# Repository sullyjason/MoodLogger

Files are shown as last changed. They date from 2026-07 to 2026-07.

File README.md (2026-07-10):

# MoodLogger

> **Attribution note:** This README (state documentation, roadmap) and the [Proposed v1 architecture](#proposed-v1-architecture-) section were drafted by **Claude (Fable 5)** on 2026-07-07 and updated as the design converged (part selection finalized 2026-07-10 with **Claude (Opus 4.8)**), based on the KiCad files in this repo, the project motivation, and the Picoclick-C3 reference project. Sections contributed by Claude are marked with 🤖. Hardware design decisions, part orders, prototypes, and project direction by Silvan Roth.

A tiny, battery-powered button logger. Press one of (at least) four buttons and the device wakes up, appends *which button was pressed at what time* to a CSV file, and goes back to sleep. To get the data, you plug the device into any USB host (cable or docking station) and it shows up as an ordinary USB flash drive — no companion app, no driver, no cloud. Grab the CSV, done.

## Design goals

- **≥ 4 buttons**, each press logged as `timestamp, button` to a CSV file
- **Wake on button press, sleep otherwise** — the device spends almost all of its life asleep
- **Battery life measured in months**: recharging should rarely, ideally almost never, be necessary
- **Host-agnostic data access**: the device enumerates as USB mass storage (a flash drive), so any OS can read the CSV without extra software
- **Accurate timestamps** from a dedicated RTC that keeps time even while the MCU sleeps

## Current state

Two prototype PCB revisions exist, both built around a **Seeed Studio XIAO ESP32-S3** module. They differ only in the RTC chip. Both are functional as prototypes but share one critical flaw (see [Known problems](#known-problems)).

### Common to both boards

- **MCU**: XIAO ESP32-S3 (U1) — provides USB-C, LiPo charging, and deep sleep
- **4 tactile buttons** (SW1–SW4, C&K PTS125) on XIAO pins D0–D3, each with a 10 k pull-up and 1 k series resistor, used as wake-up sources
- **I²C RTC** on D4/D5 (SDA/SCL)
- **CR1216 coin cell** (BT1) as RTC backup so time survives even when the main battery is empty
- **SPDT slide switch** (SW5) in the battery line as a hard power switch
- Main power from a LiPo cell on the XIAO's battery pads

### Version A — DS3231 (`EmotionTracker_DS32/`)

Board silkscreen: *EmotionLog v0 8.2025*

- **DS3231M** (U2, SOIC-16): temperature-compensated RTC with internal oscillator — very accurate, no external crystal needed, but comparatively power-hungry

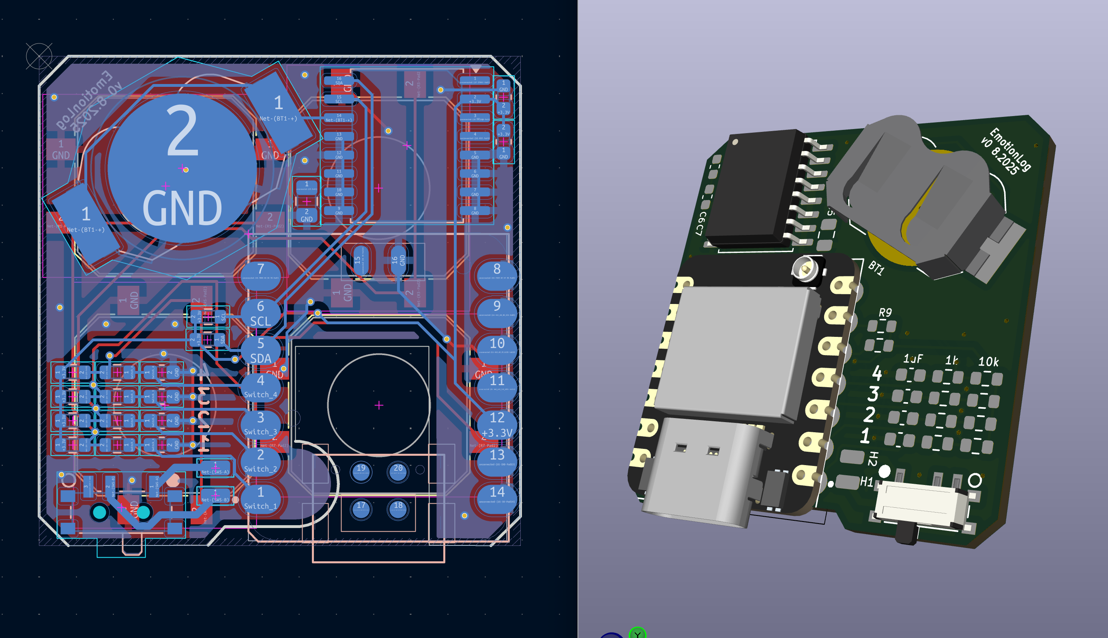
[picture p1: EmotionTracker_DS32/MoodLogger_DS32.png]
DS3231 version — layout and 3D render


### Version B — PCF8523 (`EmotionTracker_PCF8523/`)

- **PCF8523T** (U3, SOIC-8) with an external 32.768 kHz crystal (Y1) — much lower current draw than the DS3231, at the cost of needing the crystal and being less accurate over temperature
- Adds a status **LED** (D1), an extra small push button (SW6), and **BATin/BATout solder pads** in the battery path for measuring battery current / inserting protection circuitry
- `Dummy device/` contains a mechanical dummy PCB of the same outline for enclosure fitting

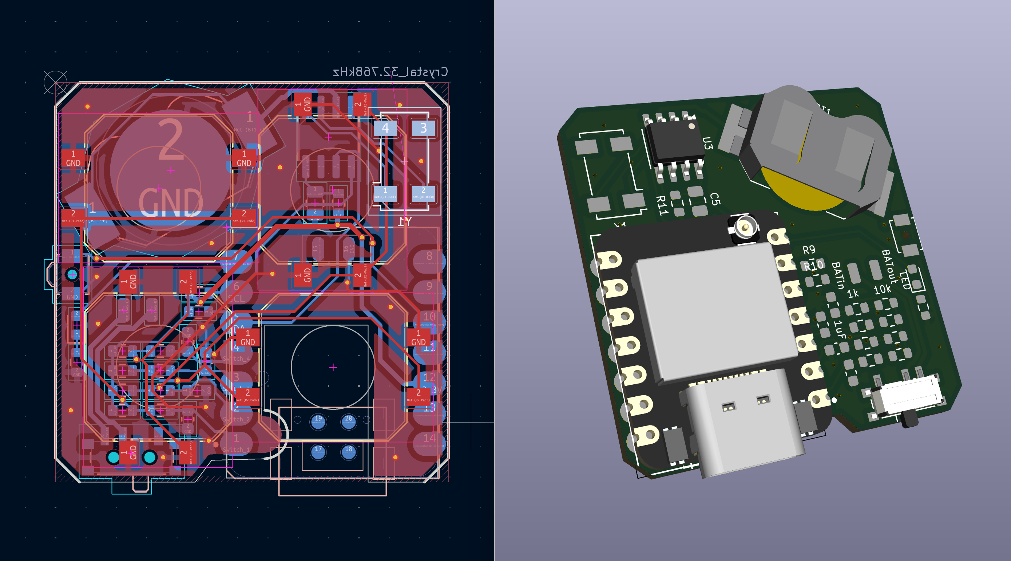
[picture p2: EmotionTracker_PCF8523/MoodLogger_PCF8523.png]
PCF8523 version — layout and 3D render


### Firmware (`Firmware/`)

Only a bring-up sketch exists so far: `Mood_track_v0/Mood_track_v0.ino` is a WS2812B/FastLED color-cycle test. The actual logging firmware (RTC, deep sleep, CSV writing, USB mass storage) has not been written yet.

## Known problems

**No battery over-discharge protection.** The XIAO ESP32-S3 has a charging circuit but no discharge cutoff, so when the device sits unused, the quiescent draw slowly pulls an unprotected LiPo below its safe minimum voltage and permanently damages it. This has already killed one battery. Nothing on either PCB revision protects against this.

**The XIAO is oversized for the job.** A full ESP32-S3 module with WiFi/BLE is overkill for "log a timestamp and sleep", and its deep-sleep and regulator overhead works against the battery-life goal.

## Roadmap

1. **Software safety first** (works on existing boards): monitor battery voltage from firmware and put the device into its lowest-power shutdown state below a cutoff threshold (with hysteresis so it doesn't oscillate near the limit). On the PCF8523 board the BATin/BATout pads can be used to hook up voltage sensing. This only *mitigates* the problem — even in deepest sleep the board still draws a few µA, so a fully drained device left on the shelf long enough can still damage the cell.
2. **Hardware protection**: add a proper battery protection IC (over-discharge cutoff) to the next board revision, or use protected cells in the meantime.
3. **Custom v1 design**: move away from the XIAO to a leaner MCU (the ATSAMD21G18) with a Picoclick-style soft power latch and native USB mass-storage, designed from the start around the goals above — see [Proposed v1 architecture](#proposed-v1-architecture-) below. Parts are ordered.

## Proposed v1 architecture 🤖

*Section author: Claude (Fable 5, refined with Opus 4.8), 2026-07-07 / 2026-07-10. Based on the boards above and the [Picoclick-C3](https://github.com/makermoekoe/Picoclick-C3) reference project (fork in `Reference Projects/`). Parts are selected and ordered but not yet built or bench-verified — treat as a design proposal, not a validated design.*

Proposed v1 block diagram

### Core idea: soft power latch instead of deep sleep

The key technique to adopt from the Picoclick is its **soft-latching power circuit**: between presses the MCU is not asleep, it is completely unpowered. A button press physically connects the battery to the regulator; the firmware's first act is to hold that connection via a latch GPIO, it logs the event, then releases the latch and the device switches itself off. The Picoclick C3 reaches **< 200 nA idle** this way — roughly three orders of magnitude below the XIAO's deep sleep — and it doubles as the discharge-protection strategy: a device that draws almost nothing cannot slowly kill its LiPo. A dedicated protection IC remains as the hard backstop.

### Why the ATSAMD21G18 (not the RP2040)

Both were considered — the deciding factor was PCB simplicity for a first custom board that may be partly hand-assembled:

- **Leaded package:** the SAMD21 is a TQFP-48 (0.5 mm, gullwing leads) — hand-solderable and inspectable. The RP2040 is a QFN-56 (0.4 mm, leadless + thermal pad) that effectively needs stencil + hot-air.
- **Fewer mandatory parts:** the SAMD21 has 256 KB internal flash and does **crystal-less USB** (clock recovery off the USB frame), so it needs no boot-flash and no crystal. The RP2040 has no internal flash (external QSPI flash is mandatory just to boot) and needs a 12 MHz crystal.
- **Native USB either way:** both enumerate cleanly as USB mass storage. (The Picoclick's own ESP32-C3 does *not* — its USB is a fixed Serial/JTAG peripheral — which is why its MCU was not reused.)

The RP2040 remains a reasonable alternative (faster boot for the latch, larger storage headroom); it just makes the board harder. The nRF52840 is the single-chip option if avoiding external flash matters more than assembly ease.

### Chosen parts (ordered)

| Block | Part | Notes |
|---|---|---|
| MCU | **ATSAMD21G18A** (TQFP-48) | 256 KB flash / 32 KB RAM, native USB, crystal-less USB via clock recovery |
| RTC | **RV-3028-C7** | ~45 nA, internal crystal, ±1 ppm; runs on the always-on rail so time survives with the MCU off. (DS3231M / PCF8523 are the higher-draw fallbacks proven on the existing boards) |
| Data storage | **W25Q32JVSSIM** (SOIC-8, 4 MB) | External SPI NOR for the FAT/CSV volume. Chosen over internal-flash-only for write endurance (~100 k vs ~25 k erase cycles) — each logged press is one FAT-metadata write, so endurance, not capacity, is the limit |
| Battery protection | **BQ29700DSER** | Over-discharge / over-current cutoff — the hard backstop for the failure that killed the prototype battery. Controller only: **needs an external dual N-channel MOSFET** (e.g. FS8205) in the cell's ground path |
| 3.3 V LDO | **AP2112K-3.3** | Sits *after* the latch, so its ~55 µA quiescent is irrelevant (only powered when the device is awake). Regulates the 3.0–4.2 V cell down to a SAMD21-safe 3.3 V |
| Charger | MCP73831-class | Charge current set by R_prog for the chosen small cell |
| Latch + button OR | P-FET high-side switch + Schottky diode-OR | Clone the Picoclick C3T latch topology (in the submodule) |

### Buttons, wake, and logging flow

Each of the four buttons does double duty: all are diode-ORed (Schottky) into the latch enable, so any press powers the board, and each also drives its own sense GPIO with a small RC hold so firmware can still read *which* button fired after boot. USB VBUS feeds the same latch OR, so plugging into any host wakes the device.

- **Log event**: boot → grab latch → read RTC over I²C → append `timestamp,button` to CSV (FatFs on NOR flash) → release latch.
- **USB attached**: enumerate as USB MSC exposing the FAT volume; pause logging while mounted.
- **Setting the clock without an app**: the firmware reads the modification timestamp of a marker file (e.g. the user saves an empty `settime.txt` to the drive) — FAT directory entries carry the host's local time, so any OS can set the RTC just by writing a file. Set-on-flash as baseline.

### Power budget (estimate)

A log event costs roughly 1 µAh (~30 mA for ~100 ms); 20 presses/day is ~0.5 mAh/month. Standby is dominated by the latch leakage plus the protection IC's quiescent draw (sub-µA). Even a 100 mAh cell lasts multiple years and is realistically limited by self-discharge — with the protection IC cutting the cell off safely at the end instead of destroying it.

### Key design notes (SAMD21)

Captured so the board doesn't have to relearn them:

- **`VDDCORE` is a regulator output** — decouple it to ground with 1 µF and connect *nothing* else. Tying it to 3.3 V is the classic dead-SAMD21 mistake.
- **No crystals.** Crystal-less USB (enable USBCRM in firmware) plus the external RV-3028 for timekeeping means neither a 12 MHz nor a 32.768 kHz crystal is needed.
- **Power the RV-3028 from the raw/always-on rail** (ahead of the latch) so it keeps time while the MCU is off; put the I²C pull-ups on the *switched* 3.3 V so they don't leak from the battery in standby.
- **BQ29700 needs external FETs.** It's a protection *controller* — pair it with a dual N-channel MOSFET in the cell's ground path; it does not switch current on its own.
- **AP2112K goes after the latch**, where its ~55 µA quiescent is a non-issue. Never put it on the always-on rail.
- **The latch is the only non-textbook subcircuit** — clone the Picoclick C3T topology from the submodule rather than inventing one, and give it enough RC hold to survive the SAMD21 boot time before firmware grabs the latch GPIO.
- **Fixed USB/SWD pins:** USB D−/D+ on PA24/PA25, SWD on PA30/PA31. I²C and SPI go on any valid SERCOM pads (confirm against the pinmux table).

## Repository layout

| Path | Contents |
|---|---|
| `EmotionTracker_DS32/` | KiCad 8 project, DS3231 revision (`production/` has JLCPCB gerbers, BOM, placement files) |
| `EmotionTracker_PCF8523/` | KiCad 8 project, PCF8523 revision + mechanical dummy board (`production/` as above) |
| `Firmware/Mood_track_v0/` | Arduino bring-up sketch (LED test only, no logging yet) |
| `Reference Projects/` | Picoclick-C3-Logger (git submodule, fork of makermoekoe/Picoclick-C3) — reference for the latch circuit and battery protection |
| `docs/` | Architecture diagrams |

## History

The concept was first prototyped on a breadboard with a XIAO ESP32-S3 and a DS3231 RTC module. That prototype worked, but the lack of discharge protection destroyed the battery — which is what motivated the roadmap above.

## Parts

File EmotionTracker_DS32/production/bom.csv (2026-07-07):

Designator | Footprint | Quantity | Value | LCSC Part #
BT1 | BatteryHolder_LINX_BAT-HLD-012-SMT | 1 | CR1216
C1, C2, C3, C4 | 0603 | 4 | 1uF
C5 | 0805 | 1 | 10uF
C6, C7 | 0603 | 2 | 100nF_Ceramic
R1, R10, R3, R5, R7, R9 | 0603 | 6 | 10k
R2, R4, R6, R8 | 0603 | 4 | 1k
SW1, SW2, SW3, SW4 | SW_Push_1P1T_NO_CK_PTS125Sx43PSMTR | 4 | SW_MEC_5E
SW5 | SW_SPDT_PCM12 | 1 | SW_SPDT
U1 | Seeeduino XIAO-MOUDLE14P-2.54-21X17.8MM | 1 | SeeeduinoXIAO
U2 | SOIC-16W_7.5x10.3mm_P1.27mm | 1 | DS3231M

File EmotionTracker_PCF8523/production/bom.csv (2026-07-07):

Designator | Footprint | Quantity | Value | LCSC Part #
BATIN, BATOUT | SolderWirePad_1x01_SMD_1x2mm | 2 | TestPoint
BT1 | BatteryHolder_LINX_BAT-HLD-012-SMT | 1 | CR1216
C1, C2, C3, C4 | 0603 | 4 | 1uF
C5 | 0805 | 1 | 10uF
D1 | 0603 | 1 | LED
R1, R10, R3, R5, R7, R9 | 0603 | 6 | 10k
R11, R2, R4, R6, R8 | 0603 | 5 | 1k
R12 | 0603 | 1 | R
SW1, SW2, SW3, SW4 | SW_Push_1P1T_NO_CK_PTS125Sx43PSMTR | 4 | SW_MEC_5E
SW5 | SW_SPDT_PCM12 | 1 | SW_SPDT
SW6 | SW_SPST_B3U-3000P-B | 1 | Push_Button
U1 | Seeeduino XIAO-MOUDLE14P-2.54-21X17.8MM | 1 | SeeeduinoXIAO
U3 | SOIC-8_3.9x4.9mm_P1.27mm | 1 | PCF8523T
Y1 | Crystal_SMD_Abracon_ABS25-4Pin_8.0x3.8mm | 1 | Crystal_32.768kHz

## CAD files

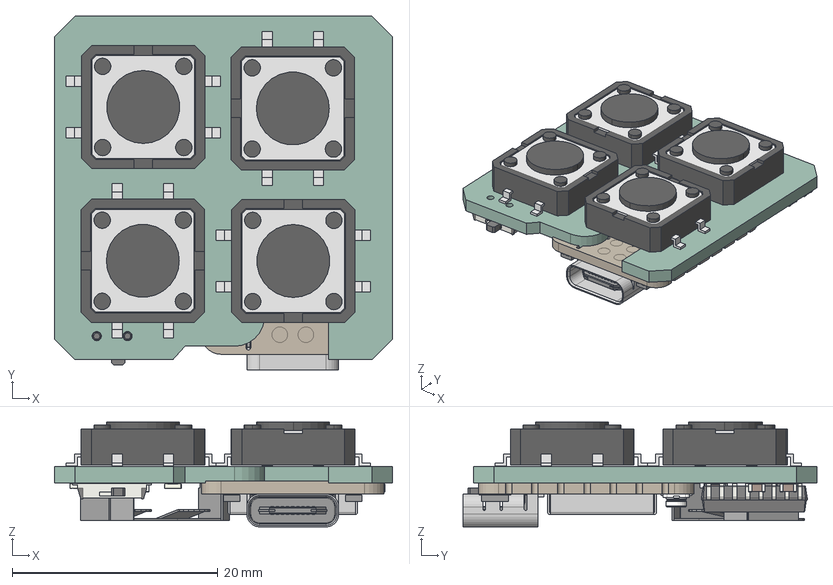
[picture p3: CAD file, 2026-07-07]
EmotionTracker_DS32/EmotionTracker_DS32.step
32.9 x 34.4 x 10.2 mm
B3FS_4005P x 4
R_0603_1608Metric x 10
C_0603_1608Metric x 6
C_0805_2012Metric
BatteryHolder_LINX_BAT-HLD-012-SMT
Fusion_sp
XIAO-ESP32S3 v2
SOIC_16W_75x103mm_P127mm
EmotionTracker_DS32_PCB

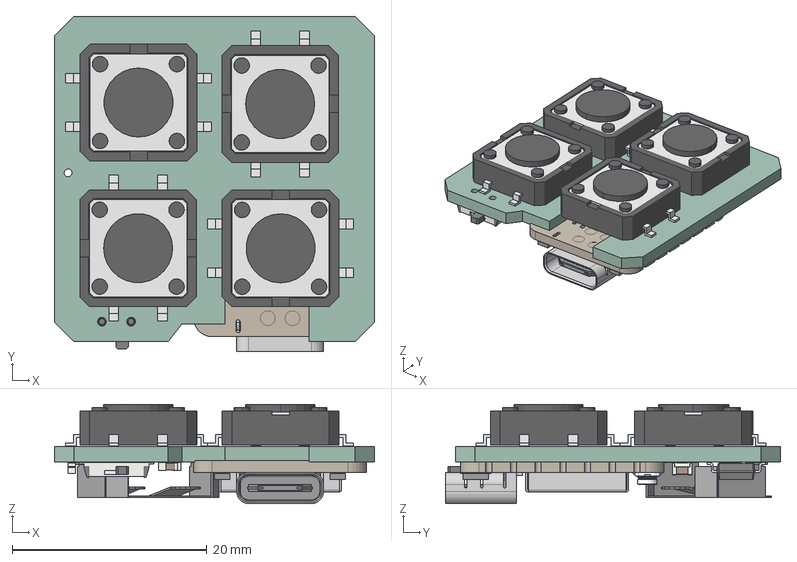
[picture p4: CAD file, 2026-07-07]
EmotionTracker_PCF8523/EmotionTracker.step
32.9 x 34.4 x 10.2 mm
B3FS_4005P x 4
R_0603_1608Metric x 12
C_0603_1608Metric x 4
C_0805_2012Metric
BatteryHolder_LINX_BAT-HLD-012-SMT
XIAO-ESP32S3 v2
LED_0603_1608Metric
Fusion_sp
SOIC_8_39x49mm_P127mm
EmotionTracker_PCB

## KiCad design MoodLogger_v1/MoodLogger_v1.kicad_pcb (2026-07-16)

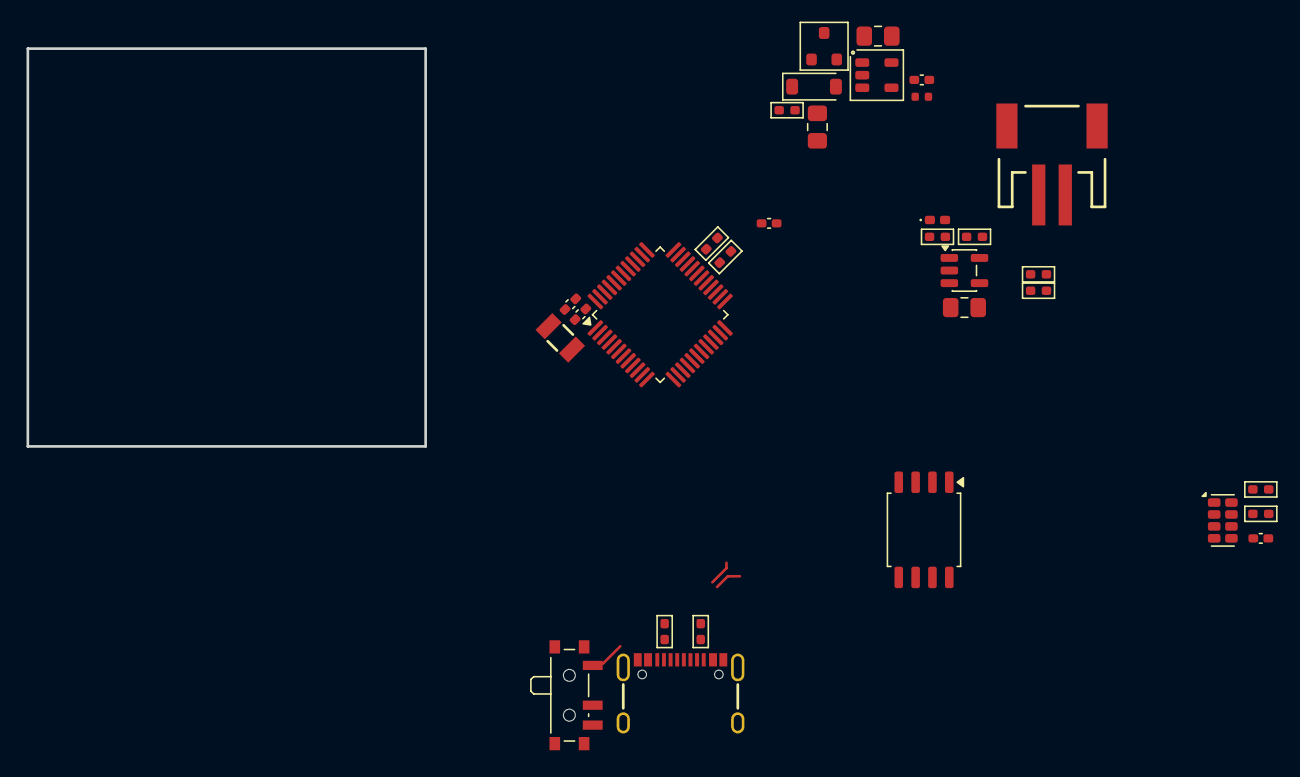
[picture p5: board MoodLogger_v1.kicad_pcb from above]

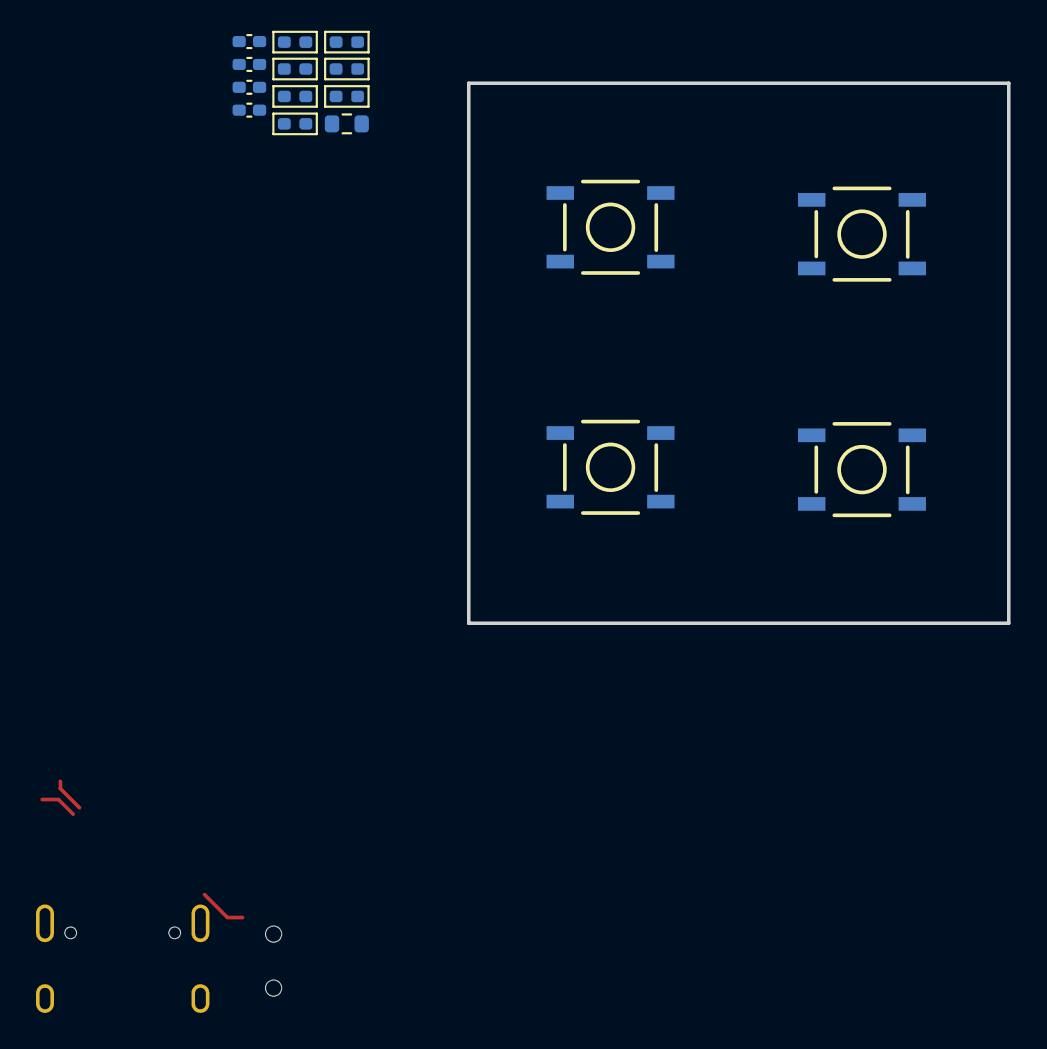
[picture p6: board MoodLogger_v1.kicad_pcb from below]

Board: 2 copper layers, 30.0 x 30.0 mm, 48 parts (16 on the bottom side), 35 nets.

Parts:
C1, C10, C15, C16, C17, C18: 1uF; C_0402_1005Metric_Pad0.74x0.62mm_HandSolder
C6: 100nF; C_0402_1005Metric_Pad0.74x0.62mm_HandSolder
C19, C20: 10uF; C_0805_2012Metric_Pad1.18x1.45mm_HandSolder
C21: 10µF; C_0805_2012Metric_Pad1.18x1.45mm_HandSolder
C22, C23: 22pF; C_0402_1005Metric_Pad0.74x0.62mm_HandSolder
CHG2: ORANGE; LED_0402_1005Metric_Pad0.77x0.64mm_HandSolder
D2: MBR120; D_SOD-123
J2: USB_C_Receptacle; USB-C_16
J3: JST_2mm_LiPo; JST_1x02_P2.0mm_Horizontal_SMD
Q1: DMG3415U; SOT-23
R1, R2: 5.1k; R_0402_1005Metric_Pad0.72x0.64mm_HandSolder
R3: 10k; R_0603_1608Metric
R6, R22, R23: 10kΩ; R_0402_1005Metric_Pad0.72x0.64mm_HandSolder
R7: 100Ω; R_0402_1005Metric_Pad0.72x0.64mm_HandSolder
R9, R12, R19: 10k; R_0402_1005Metric_Pad0.72x0.64mm_HandSolder
R10, R11, R20, R21: 1k; R_0402_1005Metric_Pad0.72x0.64mm_HandSolder
R13: 100kΩ; R_0402
R14: 1K; R_0402_1005Metric_Pad0.72x0.64mm_HandSolder
R15: 10K\; R_0402_1005Metric_Pad0.72x0.64mm_HandSolder
R16, R17, R18: 100kΩ; R_0402_1005Metric_Pad0.72x0.64mm_HandSolder
SW2, SW3, SW5, SW6: SW_MEC_5E; Push_SMD_5.2x5.2mm_h2.5mm
SW4: Slide_Switch_SPDT; SW_SPDT_PCM12
U1: ATSAMD21G18A-A; TQFP-48_7x7mm_P0.5mm
U2: RV-3028-C7; MicroCrystal_C7_SON-8_1.5x3.2mm_P0.9mm
U5: AP2112K-3.3TRG1; SOT-23-5
U6: MCP73831T-2ACI/OT; SOT-23-5
U7: W25Q32JVSS; SOIC-8_5.3x5.3mm_P1.27mm
Y1: 32.768kHz; Crystal_SMD_3.2x1.5mm

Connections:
3.3V: C18.1, C19.2, U5.5 (OUT), U7.3 (~WP/IO_{2}), U7.7 (~HOLD/~RESET/IO_{3}), U7.8 (VCC)
+3.3V: R3.1, R9.1, R12.1, R19.1, R22.1, R23.1
/5V_TO_SWITCH: J2.VBUS, SW4.1
BMON: R16.2, R17.1
BUTTON_1: C10.1, R10.1, U1.3 (PA02)
BUTTON_2: C17.1, R21.1, U1.4 (PA03)
BUTTON_3: C15.1, R11.1, U1.9 (PA04)
BUTTON_4: C16.1, R20.1, U1.10 (PA05)
D+: J2.A6 (D+), J2.B6 (D+), U1.34 (PA25)
D-: J2.A7 (D-), J2.B7 (D-), U1.33 (PA24)
FLASH_CS: U1.22 (PA13), U7.1 (~CS)
FLASH_MISO: U1.23 (PA14), U7.2 (DO/IO_{1})
FLASH_MOSI: U1.13 (PA08), U7.5 (DI/IO_{0})
FLASH_SCK: U1.14 (PA09), U7.6 (CLK)
GND: C1.1, C6.2, C10.2, C15.2, C16.2, C17.2, C18.2, C19.1, C20.2, C21.2, C22.2, C23.2, J2.GND, J2.S (SHIELD), J3.1 (-), R1.2, R2.2, R15.2, R16.1, R18.1, SW2.1, SW3.1, SW5.1, SW6.1, U1.5 (GNDANA), U1.18 (GND), U1.35 (GND), U1.42 (GND), U2.5 (VSS), U5.2, U6.2 (VSS), U7.4 (GND)
unnamed: C20.1, D2.1 (C), Q1.2 (S), R13.1, R18.2, U5.1 (IN)
unnamed: J2.A5 (CC1), R1.1
unnamed: J2.B5 (CC2), R2.1
unnamed: R3.2, R10.2, SW2.2
unnamed: R9.2, R11.2, SW5.2
unnamed: R12.2, R20.2, SW3.2
unnamed: R19.2, R21.2, SW6.2
unnamed: C23.1, U1.1 (PA00)
unnamed: C22.1, U1.2 (PA01)
unnamed: C1.2, U1.43 (VDDCORE)
unnamed: R6.2, U2.8 (EVI)
unnamed: R7.2, U2.6 (VBACKUP)
unnamed: R13.2, U5.3 (EN)
unnamed: R15.1, U6.5 (PROG)
unnamed: R14.2, U6.1 (STAT)
SCL: R23.2, U1.32 (PA23), U2.3 (SCL)
SDA: R22.2, U1.31 (PA22), U2.4 (SDA)
VBATT: C21.1, J3.2 (+), Q1.3 (D), R17.2, U6.3 (VBAT)
VBUS: D2.2 (A), Q1.1 (G), SW4.2, U6.4 (VDD)
VDD: C6.1, R6.1, R7.1, U2.7 (VDD)

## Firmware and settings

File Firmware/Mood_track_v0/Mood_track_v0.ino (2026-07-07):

#include <FastLED.h>

#include "driver/gpio.h"


#define LED_PIN    43
#define NUM_LEDS   15

CRGB leds[NUM_LEDS];

void setup() {
  Serial.begin(115200);
  delay(3000);
  Serial.println("FastLED RGB cycle test");

  gpio_set_drive_capability((gpio_num_t)LED_PIN, GPIO_DRIVE_CAP_3);
  
  FastLED.addLeds<WS2812B, LED_PIN, GRB>(leds, NUM_LEDS);
  FastLED.setBrightness(50);
}

void loop() {
  Serial.println("RED");
  leds[0] = CRGB::Red;
  FastLED.show();
  delay(1000);

  Serial.println("GREEN");
  leds[0] = CRGB::Green;
  FastLED.show();
  delay(1000);

  Serial.println("BLUE");
  leds[0] = CRGB::Blue;
  FastLED.show();
  delay(1000);
}

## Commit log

2026-07-07 Add files, initial commit
    [Dummy device.kicad_sch, EmotionTracker.kicad_sch, EmotionTracker.step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]
2026-07-07 Document project state and proposed v1 architecture in README
    - Document both XIAO ESP32-S3 prototype boards (DS3231M and PCF8523T
    revisions) from the KiCad files, including the missing battery
    over-discharge protection that killed a battery
    - Add roadmap: software voltage cutoff first, then hardware protection,
    then a custom v1 board
    - Add proposed v1 architecture section (marked as Claude contribution):
    Picoclick-style soft power latch, RP2040/RP2350 + RV-3028-C7 RTC,
    USB mass-storage CSV access, power budget estimate
    - Add standalone block diagram (docs/architecture_v1.svg)
    - Add Picoclick-C3-Logger fork as git submodule under Reference Projects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
2026-07-10 Finalize v1 part selection: SAMD21G18 baseline
    - Switch v1 MCU from RP2040 to ATSAMD21G18 with rationale (leaded TQFP,
    internal flash, crystal-less USB = simpler to assemble and route)
    - Replace suggested-parts table with the ordered BOM: ATSAMD21G18A,
    RV-3028-C7, W25Q32JVSSIM, BQ29700DSER (+ external dual N-FET),
    AP2112K-3.3 LDO, MCP73831 charger, P-FET latch
    - Add SAMD21 design notes (VDDCORE gotcha, no crystals, RTC on always-on
    rail, BQ29700 needs FETs, LDO after latch, fixed USB/SWD pins)
    - Update block diagram MCU box to ATSAMD21G18
    - Note attribution: v1 parts finalized with Opus 4.8 on 2026-07-10
2026-07-10 Moodlogger v1 - Schematic Redesign
    [MoodLogger_v1.kicad_pcb, MoodLogger_v1.kicad_sch]
2026-07-16 updated schematic and pcb
    [MoodLogger_v1.kicad_pcb, MoodLogger_v1.kicad_sch]
